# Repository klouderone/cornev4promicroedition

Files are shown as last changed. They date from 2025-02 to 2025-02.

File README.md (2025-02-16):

# Corne V4 Pro-Micro Edition

This version of the Corne V4 is beginner friendly, adding support of the easier to solder through-hole diodes, with included support for wireless builds, and brings back the option to make your Corne with whatever microcontroller you want, with the updated V4 layout, which allows wireless support with a Nice!Nano V2, and ultimately save costs when ordering as you DO NOT need PCBA. 

The Corne V4 has a completely new board outline compared to the V3 and V2, and all further development for the Corne will be using the V4 outline.

I apologise if this repository is not fully organised/explained/complete.

Please contact me if you find something wrong. reddit: klouderone, discord: klouder#3331, email: claude@keaworkshop.com

## Features

- **SMD** & **Through-Hole** diode support
- **Wired and Wireless** Support with the inclusion of battery pads, battery connector, and battery switch
- Pro Micro Footprint Daughter Board Support
- **MX** Spaced
- Hotswap **MX & Choc V1** Support
- **Breakaway 6th column** for 5 column builds
- **OLED** & **Nice!View** support
- Waffle Pattern PCB

NOTE: Like all Split Keyboards, NEVER unplug the TRRS interconnect cable while your boards are connected to your computer. 

NOTE: Do not use the TRRS jack when also using a battery. ZMK does not support wired splits.

NOTE: Do not use a battery when using wired split. QMK does not support wireless, and the battery may cause damage to your microcontroller.

Please read the **entire repo** before using anything inside it.

Original Board designed by Foostan, modified By Kea Workshop.

Buy a Kit here https://www.keaworkshop.com/product/corne-v4-pro-micro-edition

https://github.com/foostan/crkbd

## Pictures

Prebuilt 5 Column Corne







## Build 'Guide'

**Required Parts**

- 42x Kailh Choc V1 Hot Swap Sockets
- 42x Kailh MX Hot Swap Sockets
- 2x TRRS 3.5mm PJ-320A Audio Jack (if using non-wireless microcontroller)
- 42x 1N4148 SOD-123 Diodes
- 2x 3 Pin Toggle Switch (MSK-12C02 or PCM12SMTR)
- 2x Tactile Push Button Switch (3x6x4.3mm)
- 4x Mill-Max Machined 12 Pin Sockets
- 48x Mill-Max Machine Pins 
- 2x PH5 4 Pin Female Box Pin Header (for OLED)
- 2x PH5 5 Pin Female Box Pin Header (for Nice!View)
- 2x Microcontrollers (Pro Micro, Elite-C or Similar for wired, OR Nice!Nano V2 or similar for wireless)
- 2x Displays (.91 Inch OLED or Nice!View) (optional)
- 42x MX or Choc V1 Switches
- 42x MX or Choc V1 Keycaps
- 1x TRRS Male to Male Cable (if using non-wireless microcontroller)
- 2x Right Angle PH2 Battery Connector (if using a wireless microcontroller like the Nice!Nano V2)
- 2x Battery (if using a wireless microcontroller like the Nice!Nano V2) 

The build guide is **similar** to the video linked below, except without the LEDs, and the addition of the battery pads and battery switch.

The batteries are intended to be directly soldered to the board, however you can use a PH2 connector on extension leads and route it to the TRRS socket area if you would like to use a battery with a connector. I will change this so that there is also an included connector on the board on the next itteration.

Make sure you are confident will all steps before commencing build as a mistake could result in breaking your microcontroller. CHECK, CHECK AGAIN, AND THEN CHECK ONCE MORE.

https://www.youtube.com/watch?v=vzDTdLaAzXc

## Cases

The enclosed case uses 7mm M2 standoffs, for both the PCB and the oled covers. 

Ordering/Printing: Each Case has its own folder, and all parts needed for each case are located in that folder. 

Due to the new outline of the corne V4, unfortunately all previous corne version cases are incompatible.

In the cases directory, there are options for a fully enclosed case, or just a bottom plate with open sides. 

NOTE: due to the placement of the pro micro and TRRS jack, the cases for the v4 on foostans repository are NOT COMPATIBLE with the Pro Micro Edition of the corne v4, as the usb and TRRS jack are blocked by the case as they are specifically placed holes. 

The pro micro edition cases were designed to be as minimalist as possible, so they do have thin parts. This may cause a problem when ordering through JLC, as they have a minimum reccommended thickness of around 1.25mm. I have never had a problem printing all the files myself. 

The enclosed case with folding tenting leg pockets use the following folding legs. https://www.keaworkshop.com/category/components/product/case-tenting-legs

## Firmware 

No external firmware is needed, the same firmware found on the VIAL and QMK repos for the Corne V2 will work for this PCB.

## Changelog

### Revision 1 to Revision 2 - 16/02/25
- Added support for battery connector
- Added hole for under-board battery support
- Moved OLED headers .5mm lower for easier under microcontroller battery routing.
- Made under microcontroller hole larger
- Added support for through hole diodes
- Moved TRRS jack 2mm lower
- Updated Cases to match revision change
- Diodes have been relocated
- Added TPU sound dampener plate
- Added Rev 1 to Archive for back support

## Legal

THE SOFTWARE IS PROVIDED "AS IS", WITHOUT WARRANTY OF ANY KIND, EXPRESS OR IMPLIED, INCLUDING BUT NOT LIMITED TO THE WARRANTIES OF MERCHANTABILITY, FITNESS FOR A PARTICULAR PURPOSE AND NONINFRINGEMENT. IN NO EVENT SHALL THE AUTHORS OR COPYRIGHT HOLDERS BE LIABLE FOR ANY CLAIM, DAMAGES OR OTHER LIABILITY, WHETHER IN AN ACTION OF CONTRACT, TORT OR OTHERWISE, ARISING FROM, OUT OF OR IN CONNECTION WITH THE SOFTWARE OR THE USE OR OTHER DEALINGS IN THE SOFTWARE.

## Revision Control

Rev 1 - Archived 16/02/2025

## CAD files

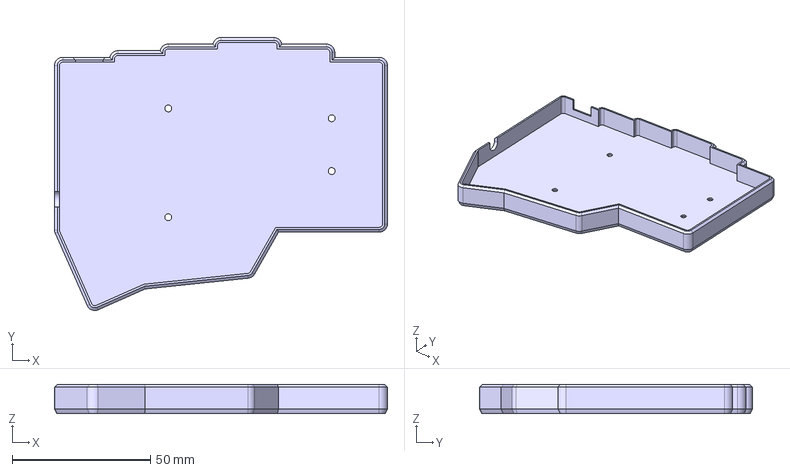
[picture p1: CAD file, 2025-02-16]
Cases/Enclosed 3x5 with Folding Tenting Feet Insert/Corne V4 Pro Micro Edition 3x5 Right Folding Feet Tenting Enclosed Case.stp
120.3 x 98.6 x 10.6 mm

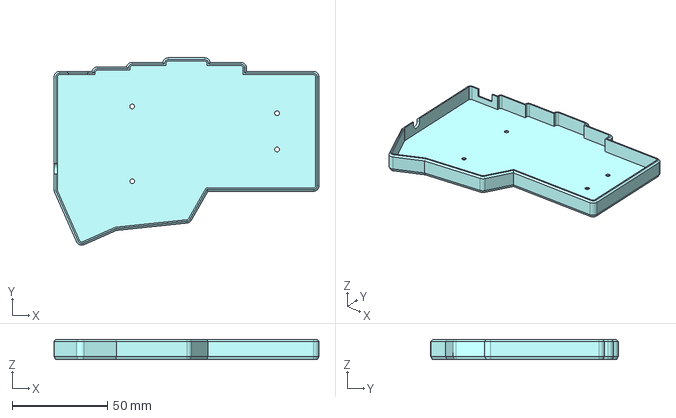
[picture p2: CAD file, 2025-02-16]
Cases/Enclosed 3x6 with Folding Tenting Feet Insert/Corne V4 Pro Micro Edition 3x6 Right Folding Feet Tenting Enclosed Case.stp
139.4 x 98.6 x 10.6 mm

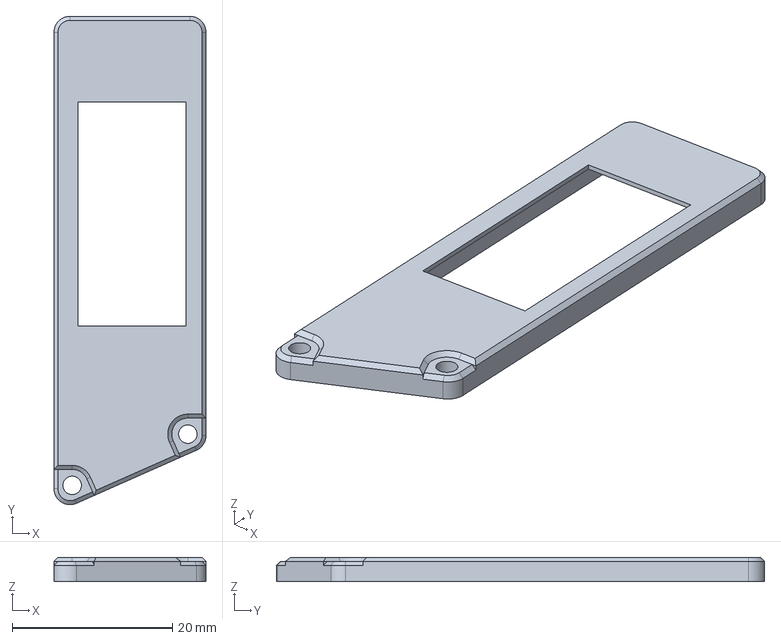
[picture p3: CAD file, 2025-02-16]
Cases/OLED Covers/Nice!View Cover Right.stp
19.0 x 61.0 x 3.05 mm

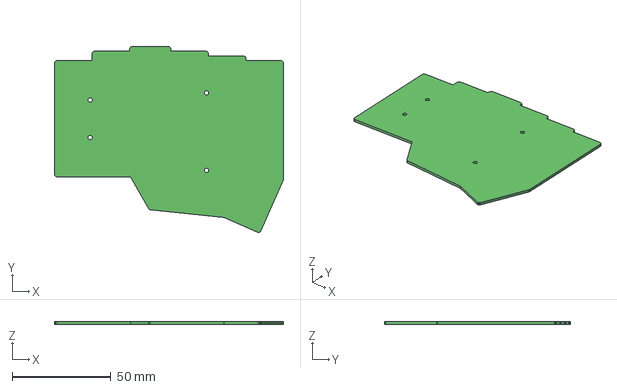
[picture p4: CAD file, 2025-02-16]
Cases/Plates 3x5/Corne V4 Pro Micro Edition 5 Column Bottom Plate.stp
116.1 x 94.3 x 1.35 mm

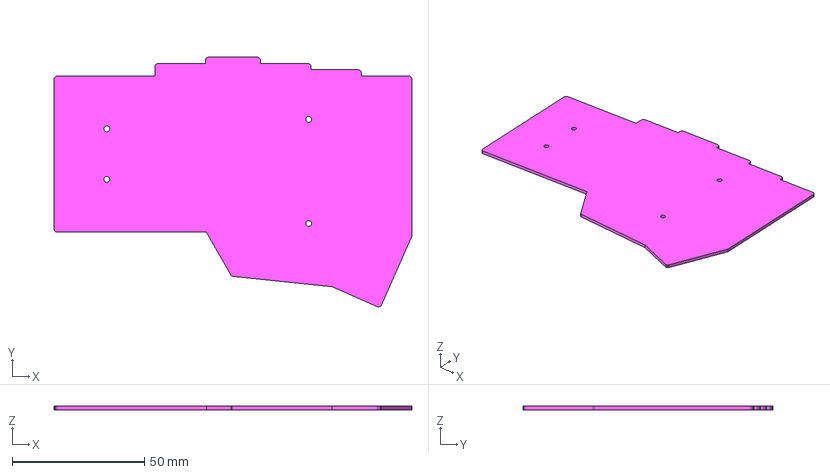
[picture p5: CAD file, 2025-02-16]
Cases/Plates 3x6/Corne V4 Pro Micro Edition 6 Column Bottom Plate.stp
135.1 x 94.3 x 1.35 mm

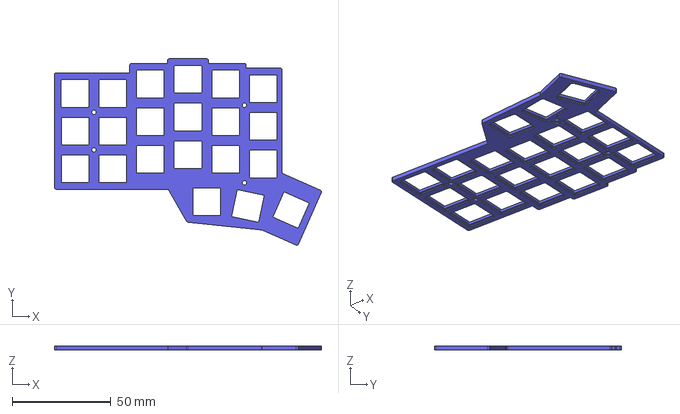
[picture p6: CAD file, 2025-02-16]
Cases/Switch Plates/Corne V4 PME Choc V1 6 Column Switch Plate Left.stp
135.1 x 94.4 x 2.00 mm

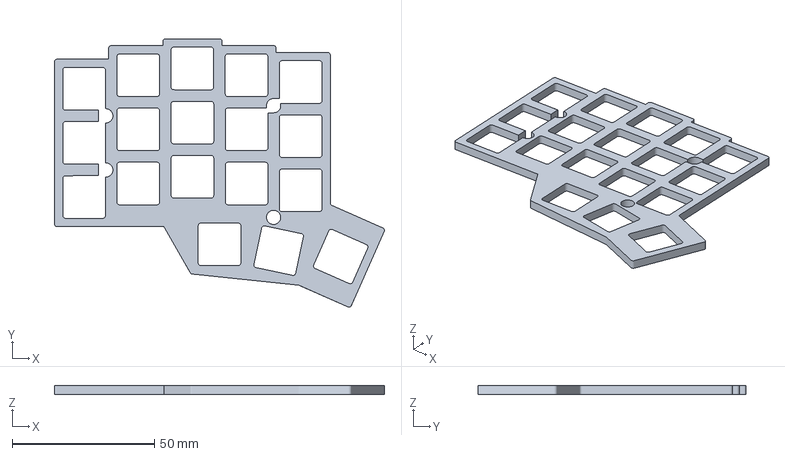
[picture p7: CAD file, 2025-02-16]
Cases/TPU Sound Dampener (MX switches only)/TPU Sound Dampener.stp
116.1 x 94.4 x 3.15 mm

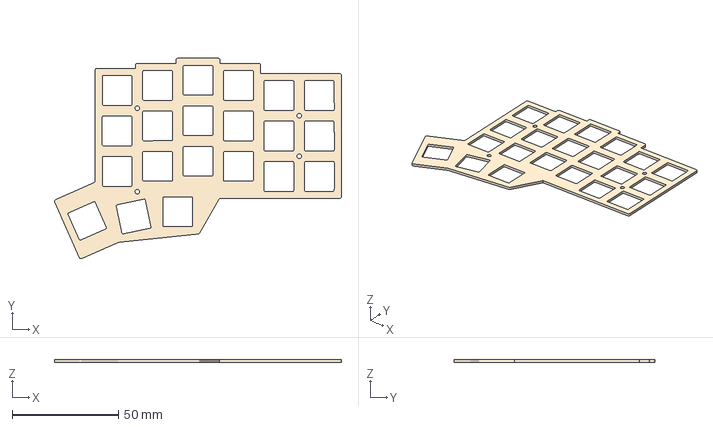
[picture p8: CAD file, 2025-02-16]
Cases/Switch Plates/Corne V4 PME MX 6 Column Switch Plate Right.stp
135.1 x 94.4 x 1.35 mm

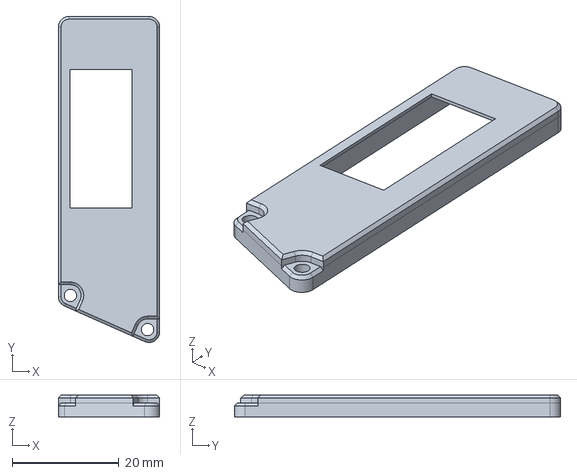
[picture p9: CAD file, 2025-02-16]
Cases/OLED Covers/OLED Cover Left.stp
19.0 x 61.0 x 4.05 mm

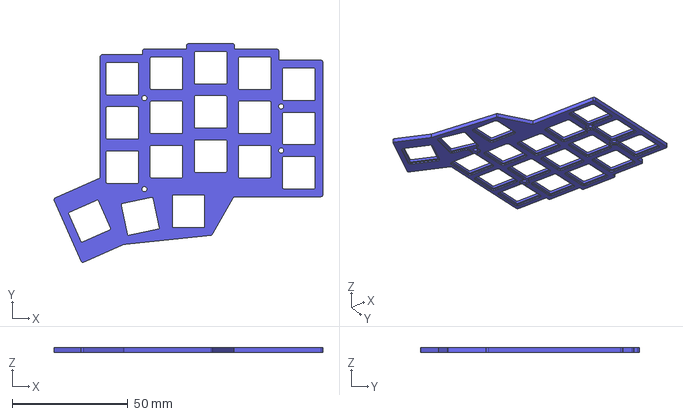
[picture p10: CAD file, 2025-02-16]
Cases/Switch Plates/Corne V4 PME Choc V1 5 Column Switch Plate Right.stp
116.1 x 94.4 x 2.00 mm

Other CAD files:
Cases/Enclosed 3x5/Corne V4 Pro Micro Edition 3x5 Left Enclosed Case.stp
Cases/Enclosed 3x6/Corne V4 Pro Micro Edition 3x6 Left Enclosed Case.stp
Cases/Enclosed 3x5 with Folding Tenting Feet Insert/Corne V4 Pro Micro Edition 3x5 Left Folding Feet Tenting Enclosed Case.stp
Cases/Enclosed 3x5/Corne V4 Pro Micro Edition 3x5 Right Enclosed Case.stp
Cases/Enclosed 3x6 with Folding Tenting Feet Insert/Corne V4 Pro Micro Edition 3x6 Left Folding Feet Tenting Enclosed Case.stp
Cases/Enclosed 3x6/Corne V4 Pro Micro Edition 3x6 Right Enclosed Case.stp
Cases/OLED Covers/Nice!View Cover Left.stp
Cases/OLED Covers/OLED Cover Right.stp
ARCHIVE/Cases/Enclosed 3x5 with Folding Tenting Feet Insert/Corne V4 Pro Micro Edition 3x5 Left Folding Feet Tenting Enclosed Case.stp
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

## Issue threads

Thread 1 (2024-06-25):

Choc v2 Compatibility

Gustavo-DMS, 2024-06-25:
The Corne V4 by foostan is already compatible with Choc v2 switches, is there any reason why this version isn't? And maybe put a warning on the README.

klouderone, 2024-06-26:
Will update to include choc v2 support. I didn't originally add them as V2 choc switches aren't as common as V1 switches.

Gustavo-DMS, 2024-06-26:
I does make a lot of sense, and I think it's more interesting to have a single PCB compatible with MX and choc switches.

Choc v2 requires a 5mm hole for it's stem versus MX's 4mm, if I cut the extra pin does the board have clearance for this extra millimeter?

BTW. I'm building two boards with a nice!nano, one with chocs and another with mx, feel free to ask any questions.

klouderone, 2024-06-28:
Unfortunately no, the centre hole isn't 5mm in diameter if I remember correctly, but it should be possible to increase that hole to 5mm diameter so Choc V2 without the top pin is compatible. I will do this when I get back from holiday on the 12th July.

Closed 2024-08-12.

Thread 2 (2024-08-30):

Choc V2 Support

eyyyyyyy3, 2024-08-30:
Why doesn't it support the choc v2 switches the original one does.

Gustavo-DMS, 2024-08-30:
He explains everything on this issue. #1

eyyyyyyy3, 2024-08-30:
Fair enough but why not just have 2 versions just like the corne

Closed 2024-09-10.

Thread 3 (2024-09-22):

improved Choc switch plates

LeoLivet, 2024-09-22:
I am close to finishing my wireless LP build with this but am having issues with the swithplate being loose. It seems the included one was mostly meant for MX style switches. By being 1.40mm thick (measured with calibers (i know realise it might also have been my slicer settings too))

I have tried to modify the switch plate after finding this [reddit thread about choc switchplates](https://old.reddit.com/r/ErgoMechKeyboards/comments/pl3xwt/kailh_choc_v1_plate_question/) where /u/kbjunky links a picture of a 2.2mm switch plate, but with an indent where the choc switches can slot into a plate of 1.32 mm.

I have sort of succesfully made a modified switch plate that has the indents by projecting the stil lines but i think with my limited skill in fusion it might be a little inaccurate when exporting to the slicer.

I think there also might be a little room to decrease the tightness of the the holes for a little tighter fit now, the switches are a tiny tiny bit loose still.

These plates were printed with Bambu P1S, with bambu PLA galaxy.

Also i didnt have the correct spacers so 4 mm ones but it now looks like there is room for lowering the sides atleast 3mm, but havent come to that point yet.
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

[New corne v4 pro micro choc switchplate test right.zip](https://github.com/user-attachments/files/17089070/New.corne.v4.pro.micro.choc.switchplate.test.right.zip)

klouderone, 2024-09-23:
hey mate, i have noticed this too. i shall print these for my own board to test and then add to the github repo! thanks!

klouderone, 2024-09-23:
printed it, works perfectly for me, only a touch of play up and down, no play side to side. could you please send me the STEP file? I shall modify for 3x5 layout too and then add to repo and give credit. cheers!

LeoLivet, 2024-09-23:
[Corne V4 Pro Micro Edition 6 Column Switch Plate v4 modified thickness with slots for choc.zip](https://github.com/user-attachments/files/17095501/Corne.V4.Pro.Micro.Edition.6.Column.Switch.Plate.v4.modified.thickness.with.slots.for.choc.zip)
I attached it here in a zip file. I was mostly worried about the play because i was just using the stp file you provided. And fusion was doing some things that made the holes look weird.

But basically i just projected two different plates.

One with 0.9mm thickness and then another with 1.3mm thickness
Then i just offset the 0.9mm faces with -1 mm for the holes.

i did a few test prints of some different thickness and it seems in the end to get the desired thickness sort of comes to down to the resolution you use on the z-height in the slicer. i could seeming only get it to be between 1.28 or 1.32 according to the slicer. :)

klouderone, 2024-09-23:
i realised i could just model it myself after i sent that message haha. With the desired thickness, depending on the slicer you use, there is an option called adaptive Z height, which allows you to get pretty close to the modelled thickness using different layer heights. Shall print today!

klouderone, 2024-09-26:
Printed and works very well, shall be adding. Thanks for bringing this to my attention!

LeoLivet, 2024-09-27:
nice! i am thinking about trying to make another modification to the case itself to make even thinner, i dont know if its bad by convention to have the hotswap sockets touch the bottom. But i think the height can be lowered by another few mm too.
(perhaps if you have the step files with timeline for fusion and wanna share it that'd be cool? :) )
Anyways i will mark this as closed if that's the correct way to do so. :)

klouderone, 2024-09-28:
i don't use fusion unfortunately, i use Rhino. the step files are there if you want to use them to make your own model though! it is also fine to have them touch the bottom, plastic isn't conductive!

Closed 2024-09-27.

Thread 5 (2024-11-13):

how to connect the battery

charleyzhu, 2024-11-13:
Could you tell me how to connect the battery

Gustavo-DMS, 2024-11-13:
There are two little silver pads on the pcb next te the upper most part of the micro-controller.
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

charleyzhu, 2024-11-14:
Thank you so much

Closed 2024-11-19.

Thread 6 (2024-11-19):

about firmware

charleyzhu, 2024-11-19:
Hello, I am currently using the RP2040 Pro Micro module. After uploading the firmware to the left keyboard, it always stays in the bootloader and cannot load the firmware properly. The right keyboard's LED is displaying content. What could be the issue? Also, is this firmware open source?

klouderone, 2024-11-19:
Firmware is open source, and is under Corne on ZMK, QMK and QMK-VIAL. The precompiled firmware is proven to work, and is added as a quick check to make sure everything works as intended. Sounds like a microcontroller problem?

klouderone, 2024-11-20:
How are you writing to the RP2040? Are you entering the bootloader by double clicking the reset button, and then dragging the UF2 file into the controller on your file explorer? I am not sure what the problem would be other than the microcontroller or the correct flashing method.

charleyzhu, 2024-11-21:
> How are you writing to the RP2040? Are you entering the bootloader by double clicking the reset button, and then dragging the UF2 file into the controller on your file explorer? I am not sure what the problem would be other than the microcontroller or the correct flashing method.

I’m sure I’m writing the firmware correctly, and I’m also considering the controller issue. I’ve purchased two RP2040 boards with 16M Flash (the current Flash size is 4M). I’ll try writing the firmware again once they arrive tomorrow.

Closed 2024-12-15.

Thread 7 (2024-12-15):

SVG files

SparrowMike, 2024-12-15:
Hey!

Thanks for sharing this cool project, I was wondering if you have svg files for the screen covers as I would like to cut some instead of using 3D printed.

Many thanks!

Cheers

klouderone, 2024-12-15:
done, they are located under cases/oled covers. you will need some taller standoffs (around 10mm to 11mm) than 7mm ones though as the acrylic is flat and the 3D printed ones are not!

klouderone, 2024-12-16:
Hm, strange. I'll upload as a DXF as that'll have proper scaling, I'm not the biggest fan of SVG's

cuongha0701, 2025-06-11:
> done, they are located under cases/oled covers. you will need some taller standoffs (around 10mm to 11mm) than 7mm ones though as the acrylic is flat and the 3D printed ones are not!

Hi, can you please upload acrylic oled cover in Kicad format?

Closed 2024-12-15.

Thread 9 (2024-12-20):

Battery Support

rodridevops, 2024-12-20:
Thank you for this beautiful version of Corne!

We are working on a personal project and greatly miss the microcontroller support from the 4th version.

Could you please share your timeline for adding support for an external battery connector to the PCB (instead of the Pro Micro)? Also, are you considering adding an on/off switch to the design?

klouderone, 2024-12-20:
Hey mate,

There is currently a switch on the PCB for battery control, as well as battery pads. Only thing missing is a battery connector. Still got to get around to do it, though I don't have too much time at the moment to do it with work. I'll see what I can come up with this weekend, if I get a moment I'll get around to doing it.

Will update this issue when I update the repo!

rodridevops, 2024-12-20:
Thank you so much Claude. I will test it out as it is today!

I will let you know here and on reddit :)

ffiebig, 2024-12-22:
Thanks for the awesome work on this project @klauderone, excited for the upcoming update

klouderone, 2024-12-22:
Haven't managed to get around to it this weekend, family turned up a day early for Christmas, will be update Boxing Day!

klouderone, 2025-02-16:
Hey there all, sorry i have been absent and didn't get around to doing this earlier. I had some great opportunities come up in my personal life that put this on hold. Rev 2 is now live, with right angle battery connector support, and through hole diode support. Sorry for the delay!

Closed 2025-02-16.

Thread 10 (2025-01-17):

Requesting symbols!

thomaseliot, 2025-01-17:
Hi there! Thanks for sharing this keyboard design. I'm wondering if you would be willing to push the footprints and symbols for the switches? Such as `ClaudeFoot:SW_MXchoc_HS_1u` I would love to use this design as a base for another one.

thomaseliot, 2025-01-17:
I'm also trying to see if I can get the board populated by JLPCB, I think those would help!

klouderone, 2025-02-16:
Hey mate, please check my github repositiories for my Kicad footprint library! Unfortunately i dont have any symbols, to give you as i never made any, just used other ones built in or found in other places. To be completely honest, my kicad library is a mess, and i am only just realising it as I never spent the time to actually organise it or find a way to make it easily shareable when i first started. Hope this can help. Also sorry for the late reply, i had some things come up!

Closed 2025-02-16.

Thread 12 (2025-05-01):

Wired and wireless PCB

t0bybr, 2025-05-01:
Hi, thanks for the project. Exactly what I was looking for. One question, could I solder the TRRS Jacks even if I initially plan to use it wireless? So that I could switch to wired when removing the battery and swapping the MCU?

Thanks
Toby

jerlam06, 2025-05-01:
Yes, I did it ;)

Closed 2025-07-11.

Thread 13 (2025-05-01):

Are PCB pairs bound together?

jerlam06, 2025-05-01:
Hi, I have a few pairs of your PCB, but I am unable to mix left and right together, for instance when I wire left from pair 1 with right from pair 2, it will not work, the right pair doesnt work in this case. I tried many different mix and never got it to work, even after reflashing and all. Is that normal?
Thanks

jerlam06, 2025-05-01:
m

Closed 2025-05-01.

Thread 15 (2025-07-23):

about the minimum order quantity for PCB fabrication

darkhandz, 2025-07-23:
I looked at the PCB file, and it seems that one-time manufacturing produces a single PCB board containing both the left-hand and right-hand keyboards.

However, I noticed that the minimum order quantity at JLCPCB is 5 boards. If I only want to make one set of keyboards, I would have to order 5 sets of keyboard PCBs, wasting 4 boards (and these are quite large in size). This makes the cost seem quite high.

On the other hand, I saw that the Sofle wireless design uses the same PCB for both left and right hands, meaning I only need to order 5 boards and use 2 of them, wasting only 3 boards (which are smaller in size). I'm not sure if my understanding is correct.

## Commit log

2024-05-01 Kicad and Gerber File Addition
    [Corne V4 Kea Workshop Edition.kicad_sch, left.kicad_sch, right.kicad_sch]
2024-08-12 Changed OLED cover hole locations
2024-09-04 Added Folding Tenting Feet Enclosed Case Option
    [Corne V4 Pro Micro Edition 3x5 Left Folding Feet Tenting Enclosed Case.stp, Corne V4 Pro Micro Edition 3x5 Right Folding Feet Tenting Enclosed Case.stp, Corne 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]
2024-09-06 Battery Hole, OLED Hole update
    changed location of OLED hole to match switch plate, added a hole for leads for a connector battery to pass through
2024-09-07 Increased size of battery switch pads
2024-09-07 increased size of smd diode pads
2024-09-07 updated tenting case
    [Corne V4 Pro Micro Edition 3x5 Left Folding Feet Tenting Enclosed Case.stp, Corne V4 Pro Micro Edition 3x5 Right Folding Feet Tenting Enclosed Case.stp, Corne 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]
2024-10-01 Organise Case Directory, Switch Plate Additions
    added Choc Specific Switch Plates
    [Corne V4 PME Choc V1 5 Column Switch Plate Left.stp, Corne V4 PME Choc V1 5 Column Switch Plate Right.stp, Corne V4 PME Choc V1 6 Column Switch Plate Left.stp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]
2024-10-07 save with kicad 8
    [Corne V4 Pro Micro Edition Switch Plate.kicad_pcb]
2024-10-07 add logo and copper zone (copied from main PCB)
    [Corne V4 Pro Micro Edition Switch Plate.kicad_pcb]
2024-10-07 regenerated production file I've followed this guide https://jlcpcb.com/help/article/how-to-generate-gerber-and-drill-files-in-kicad-8
2024-12-19 Add SVG acrylic bottom plate files Exported SVG from FreeCAD, and removed redundant paths in Illustrator.
2024-12-19 Add SVG acrylic switch plate files Exported SVG from FreeCAD, and removed redundant paths in Illustrator. MX and choc can share the same switch plate if the number of column is the same.
2025-02-16 Archiving Revision 1
    Archiving Revision 1 in prep for Revision 2 Upload
    [Corne V4 PME Choc V1 5 Column Switch Plate Left.stp, Corne V4 PME Choc V1 5 Column Switch Plate Right.stp, Corne V4 PME Choc V1 6 Column Switch Plate Left.stp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]
2025-02-16 Upload of Rev 2
    Upload of Rev 2 with requested changes and additional ones. Check changelog on the README.
    [Corne V4 PME Choc V1 5 Column Switch Plate Left.stp, Corne V4 PME Choc V1 5 Column Switch Plate Right.stp, Corne V4 PME Choc V1 6 Column Switch Plate Left.stp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]
2025-10-21 Case Modification
    fixing unaligned TRRS cutout
